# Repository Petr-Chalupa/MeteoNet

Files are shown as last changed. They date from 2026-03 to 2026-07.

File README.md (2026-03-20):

# MeteoNet

Simple meteorological net with single root node and multiple sensor nodes.  
Focusing on low power consumption, low data TX and near/far communication.

### FW
> Written in C++  
> No runtime memalloc strategy  
> No unnecessary C++ features

### HW
> Developed in KiCAD  
> Simple design  
> One HW, multiple roles strategy

_For more thorough documentation, please see [docs](/docs)._

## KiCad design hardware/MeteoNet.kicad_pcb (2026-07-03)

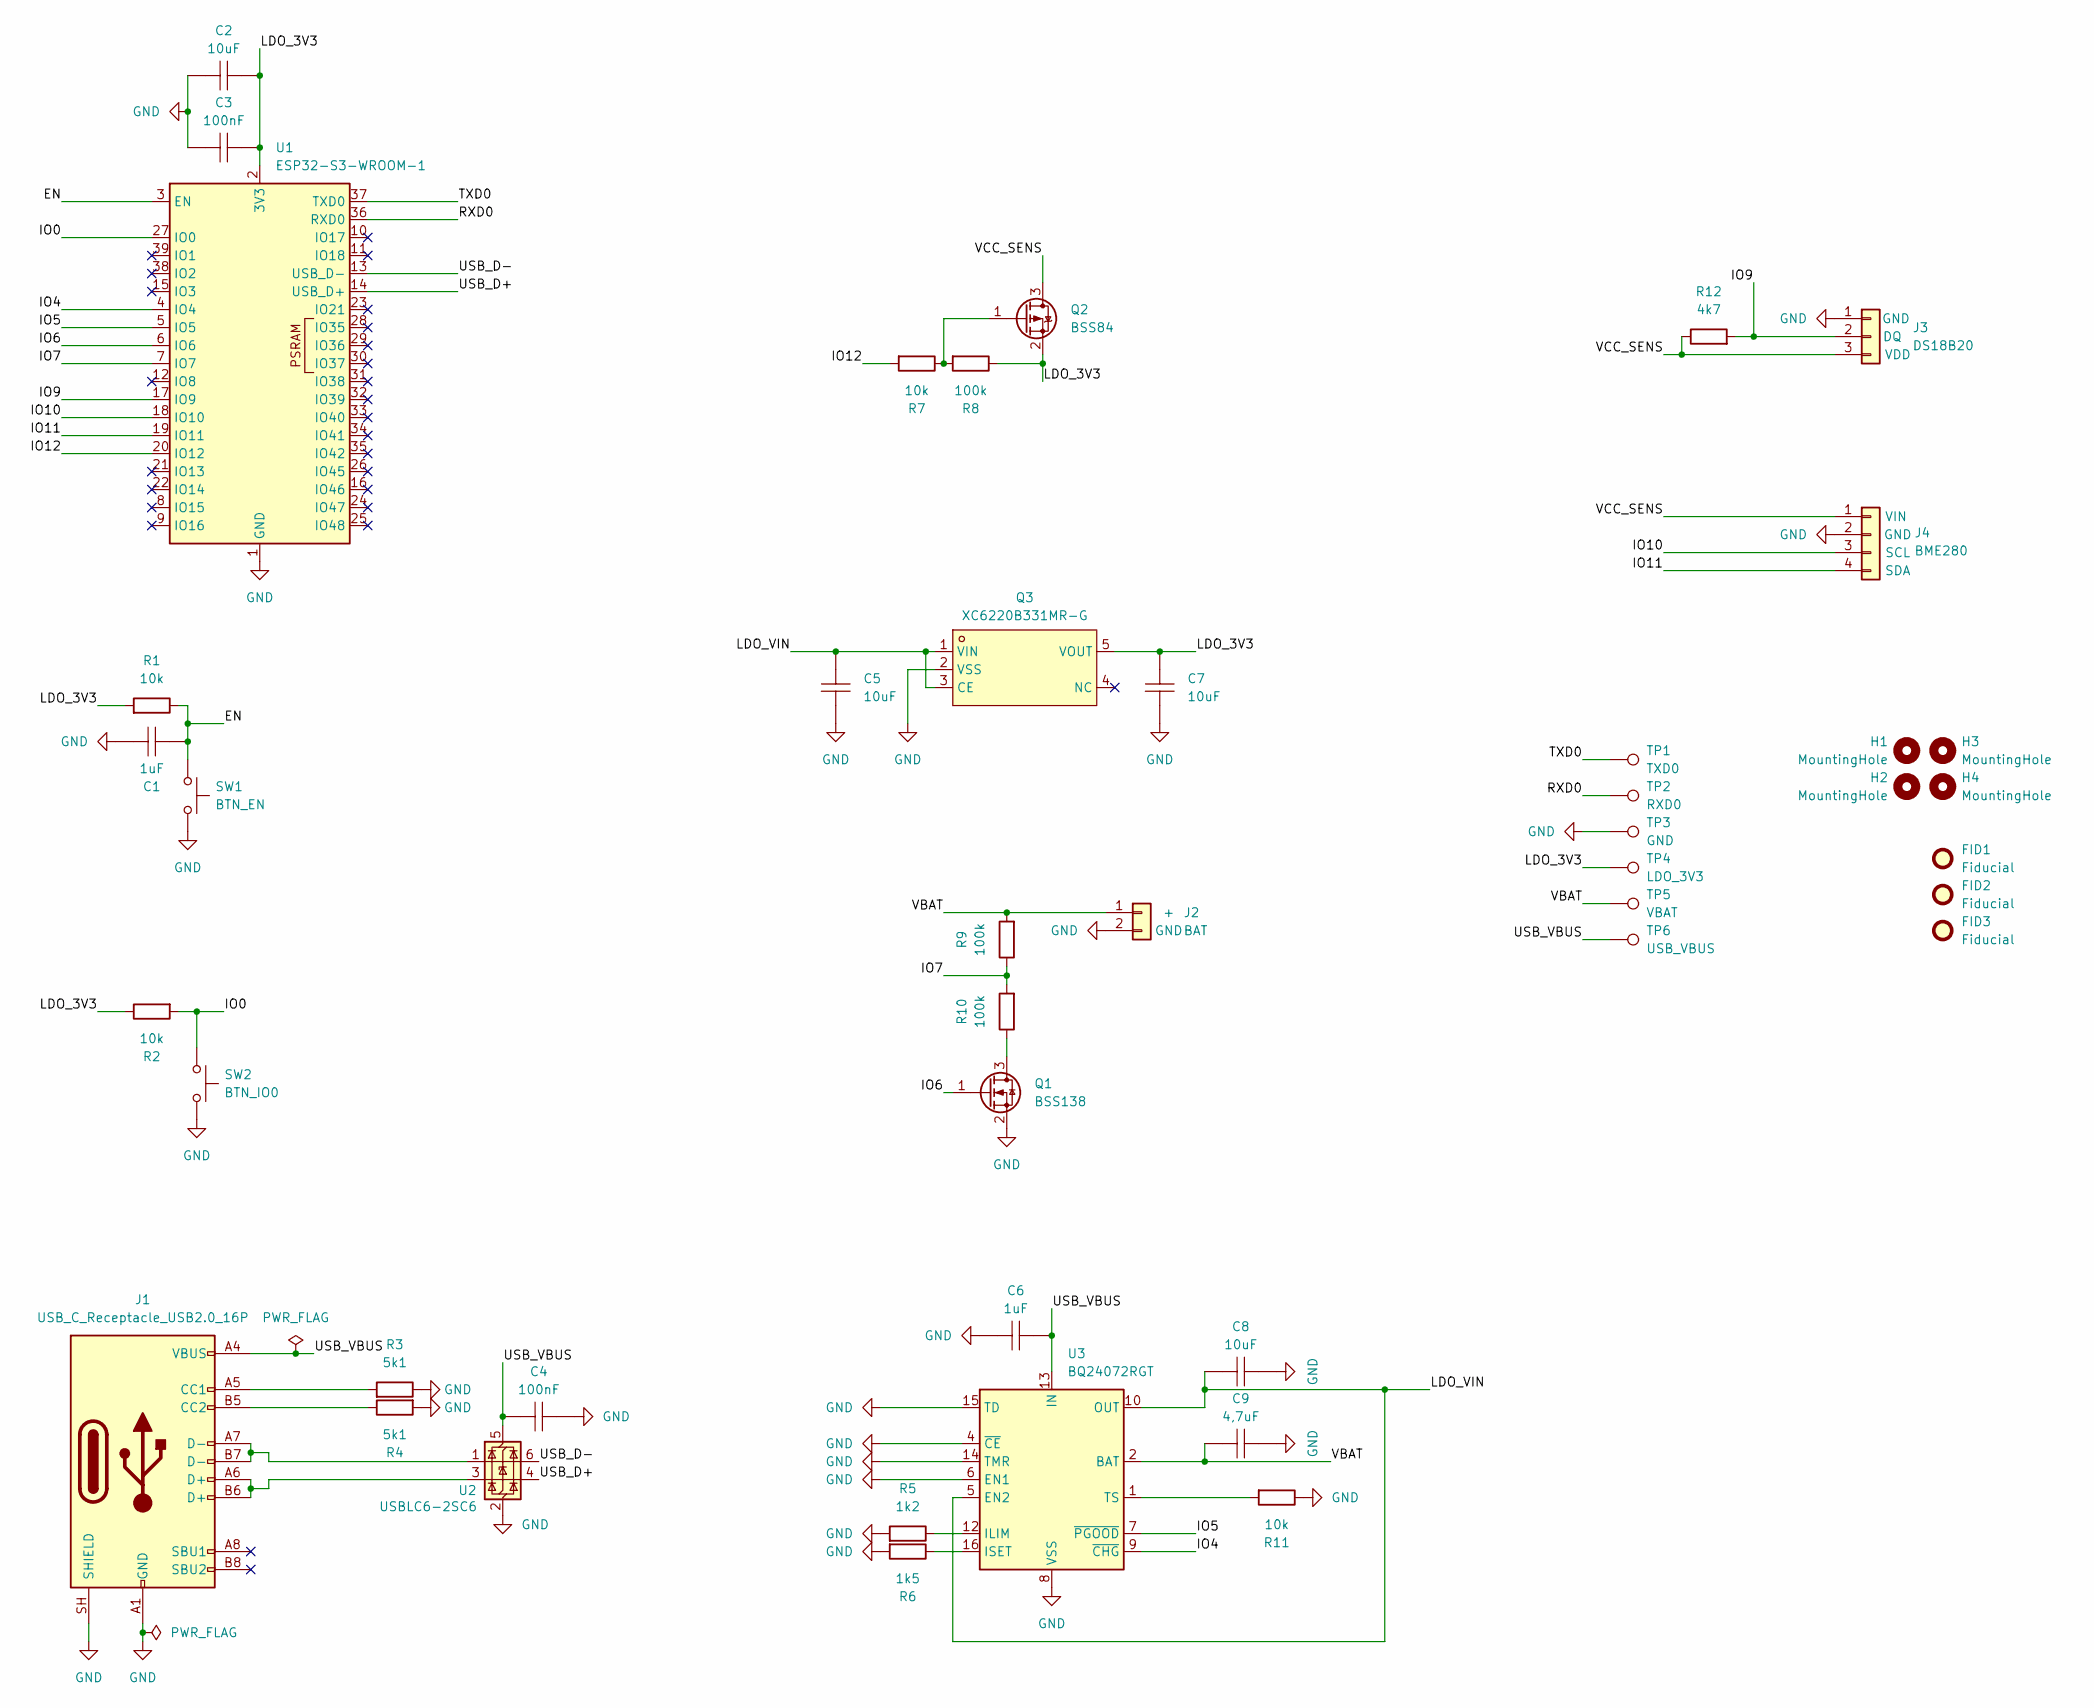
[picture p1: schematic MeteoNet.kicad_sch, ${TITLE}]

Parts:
C1: 1uF; C_0603_1608Metric; Voltage Rated 10V; Tolerance ±10%; LCSC Part C19702
C2, C5, C7: 10uF; C_0805_2012Metric; Voltage Rated 10V; Tolerance ±10%; LCSC Part C19702
C3, C4: 100nF; C_0603_1608Metric; Voltage Rated 16V; Tolerance ±10%; LCSC Part C1525
C6: 1uF; C_0603_1608Metric; Voltage Rated 16V; Tolerance ±10%; LCSC Part C1525
C8: 10uF; C_0805_2012Metric; Voltage Rated 16V; Tolerance ±10%; LCSC Part C1525
C9: 4,7uF; C_0805_2012Metric; Voltage Rated 16V; Tolerance ±10%; LCSC Part C1525
FID1, FID2, FID3: Fiducial; Fiducial_1mm_Mask2mm
H1, H2, H3, H4: MountingHole; MountingHole_2.5mm_Pad
J1: USB_C_Receptacle_USB2.0_16P; USB_C_Receptacle_HRO_TYPE-C-31-M-12; LCSC Part # C165948
J2: BAT; JST_PH_B2B-PH-SM4-TB_1x02-1MP_P2.00mm_Vertical; LCSC Part # C160352
J3: DS18B20; PinSocket_1x03_P2.54mm_Vertical_SMD_Pin1Left; LCSC Part # C42379196
J4: BME280; PinSocket_1x04_P2.54mm_Vertical_SMD_Pin1Left; LCSC Part # C42379197
Q1: BSS138; SOT-23; LCSC Part # C52895
Q2: BSS84; SOT-23; LCSC Part # C112238
Q3: XC6220B331MR-G; SOT-23-5; Dropout Voltage 655mV@(1A); Output Voltage 3.3V; LCSC Part C86534
R1, R2, R7, R11: 10k; R_0603_1608Metric; LCSC Part # C25804
R3, R4: 5k1; R_0603_1608Metric; LCSC Part # C23186
R5: 1k2; R_0603_1608Metric; LCSC Part # C22765
R6: 1k5; R_0603_1608Metric; LCSC Part # C22843
R8, R9, R10: 100k; R_0603_1608Metric; LCSC Part # C25803
R12: 4k7; R_0603_1608Metric; LCSC Part # C23162
SW1: BTN_EN; SW_SPST_PTS645Sx43SMTR92; LCSC Part # C2801804
SW2: BTN_IO0; SW_SPST_PTS645Sx43SMTR92; LCSC Part # C2801804
TP1: TXD0; TestPoint_Pad_D1.5mm
TP2: RXD0; TestPoint_Pad_D1.5mm
TP3: GND; TestPoint_Pad_D1.5mm
TP4: LDO_3V3; TestPoint_Pad_D1.5mm
TP5: VBAT; TestPoint_Pad_D1.5mm
TP6: USB_VBUS; TestPoint_Pad_D1.5mm
U1: ESP32-S3-WROOM-1; JLCPCB Part # C2913198
U2: USBLC6-2SC6; SOT-23-6; LCSC Part # C7519
U3: BQ24072RGT; VQFN-16-1EP_3x3mm_P0.5mm_EP1.6x1.6mm; LCSC Part # C140288

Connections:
/EN: C1.2, R1.1, SW1.1, U1.3 (EN)
/IO0: R2.2, SW2.1, U1.27 (IO0)
/IO4: U1.4 (IO4), U3.9 (~CHG)
/IO5: U1.5 (IO5), U3.7 (~PGOOD)
/IO6: Q1.1 (G), U1.6 (IO6)
/IO7: R9.1, R10.2, U1.7 (IO7)
/IO9: J3.2, R12.2, U1.17 (IO9)
/IO10: J4.3, U1.18 (IO10)
/IO11: J4.4, U1.19 (IO11)
/IO12: R7.2, U1.20 (IO12)
/LDO_3V3: C2.2, C3.2, C7.2, Q2.2 (S), Q3.5 (VOUT), R1.2, R2.1, R8.1, TP4.1 (1_1), U1.2 (3V3)
/LDO_VIN: C5.1, C8.2, Q3.1 (VIN), Q3.3 (CE), U3.5 (EN2), U3.10 (OUT), U3.11 (OUT)
/RXD0: TP2.1 (1_1), U1.36 (RXD0)
/TXD0: TP1.1 (1_1), U1.37 (TXD0)
/USB_D+: U1.14 (USB_D+), U2.4 (I/O2)
/USB_D-: U1.13 (USB_D-), U2.6 (I/O1)
/USB_VBUS: C4.1, C6.2, J1.A4 (VBUS), J1.A9 (VBUS), J1.B4 (VBUS), J1.B9 (VBUS), TP6.1 (1_1), U2.5 (VBUS), U3.13 (IN)
/VBAT: C9.1, J2.1, R9.2, TP5.1 (1_1), U3.2 (BAT), U3.3 (BAT)
/VCC_SENS: J3.3, J4.1, Q2.3 (D), R12.1
GND: C1.1, C2.1, C3.1, C4.2, C5.2, C6.1, C7.1, C8.1, C9.2, J1.A1 (GND), J1.A12 (GND), J1.B1 (GND), J1.B12 (GND), J1.SH (SHIELD), J2.2, J3.1, J4.2, Q1.2 (S), Q3.2 (VSS), R3.1, R4.2, R5.2, R6.2, R11.1, SW1.2, SW2.2, TP3.1 (1_1), U1.1 (GND), U1.40 (GND), U1.41 (GND), U2.2 (GND), U3.4 (~CE), U3.6 (EN1), U3.8 (VSS), U3.14 (TMR), U3.15 (TD), U3.17 (VSS)
unnamed: J1.A5 (CC1), R3.2
unnamed: J1.B5 (CC2), R4.1
unnamed: J1.A6 (D+), J1.B6 (D+), U2.3 (I/O2)
unnamed: J1.A7 (D-), J1.B7 (D-), U2.1 (I/O1)
unnamed: Q1.3 (D), R10.1
unnamed: Q2.1 (G), R7.1, R8.2
unnamed: R5.1, U3.12 (ILIM)
unnamed: R6.1, U3.16 (ISET)
unnamed: R11.2, U3.1 (TS)

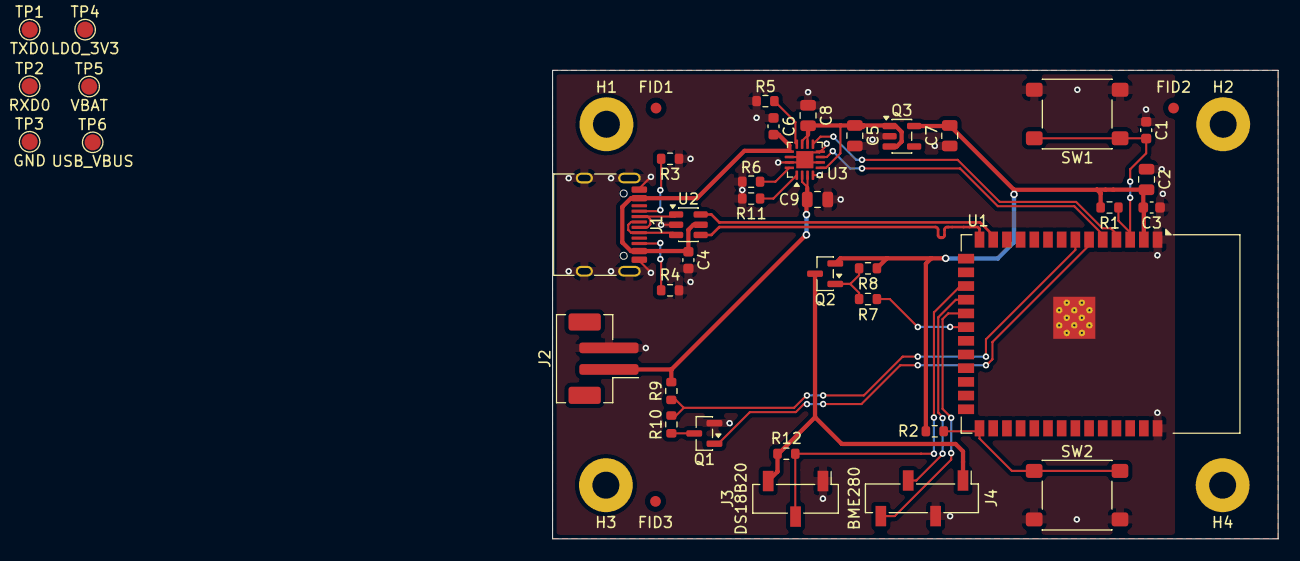
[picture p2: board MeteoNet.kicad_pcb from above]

Board: 2 copper layers, 67.3 x 43.5 mm, 46 parts (0 on the bottom side), 29 nets.

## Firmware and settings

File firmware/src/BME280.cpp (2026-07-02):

#include "sensor.hpp"
#include <Adafruit_BME280.h>
#include <Wire.h>

#define SDA 21
#define SCL 22
#define ADDRESS 0x76

struct BME280Data {
  float temperature;
  float humidity;
  float pressure;
};

class BME280Sensor : public ISensor<BME280Data> {
private:
  Adafruit_BME280 bme;
  bool initialized = false;

public:
  bool init() override {
    Wire.begin(SDA, SCL);
    initialized = bme.begin(ADDRESS);

    return initialized;
  }

  void deinit() override {
    pinMode(SDA, INPUT);
    pinMode(SCL, INPUT);
    Wire.end();

    initialized = false;
  }

  bool read(BME280Data &out) override {
    if (!initialized) return false;

    out.temperature = bme.readTemperature();
    out.humidity = bme.readHumidity();
    out.pressure = bme.readPressure() / 100.0F;

    return true;
  }
};

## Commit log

2026-03-19 Basic repo structure setup
    [MeteoNet.kicad_pcb, MeteoNet.kicad_sch]
2026-03-19 Added esp32S3 symbol
    [MeteoNet.kicad_sch]
2026-03-21 LDO sch.
    [MeteoNet.kicad_pcb, MeteoNet.kicad_sch]
2026-03-22 Headers: buffer, lock, sensor
2026-03-22 ESP V3V C
    [MeteoNet.kicad_sch]
2026-03-22 Stub sensor headers
2026-03-23 Stub sensor deinit
2026-03-27 Reworked sensor impl
2026-07-03 PCB routing
    [MeteoNet.kicad_pcb, MeteoNet.kicad_sch]
2026-07-03 TP value -> F.silkscreen
    [MeteoNet.kicad_pcb]
